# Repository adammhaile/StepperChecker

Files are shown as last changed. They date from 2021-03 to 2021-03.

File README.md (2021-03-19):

# StepperChecker

StepperChecker is  a stepper motor driver dev and test board, designed to be easy to build, setup, and use.
It will take any stepstick style motor driver and any Feather compatible microcontroller board.
The basic intent is to have firmware loaded that will move the motor forward or reverse based on which button is pressed, at a sped defined by the potentiometer. But, of course, the sky is the limit given the many Feather boards available.

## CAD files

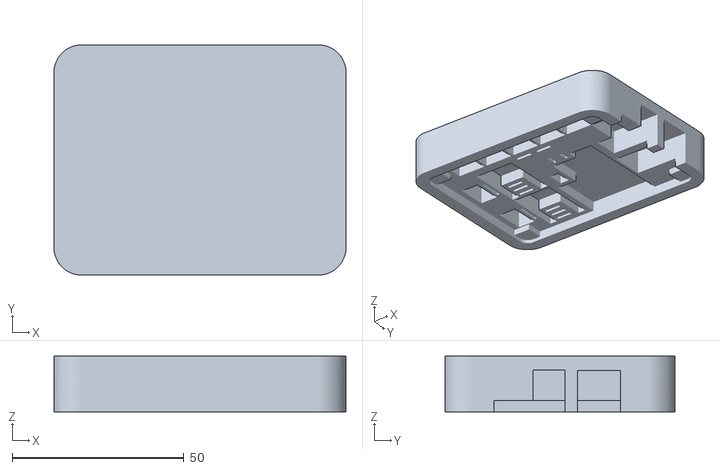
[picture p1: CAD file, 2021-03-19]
StepperChecker/SolderJig.stl
85.0 x 67.0 x 16.2

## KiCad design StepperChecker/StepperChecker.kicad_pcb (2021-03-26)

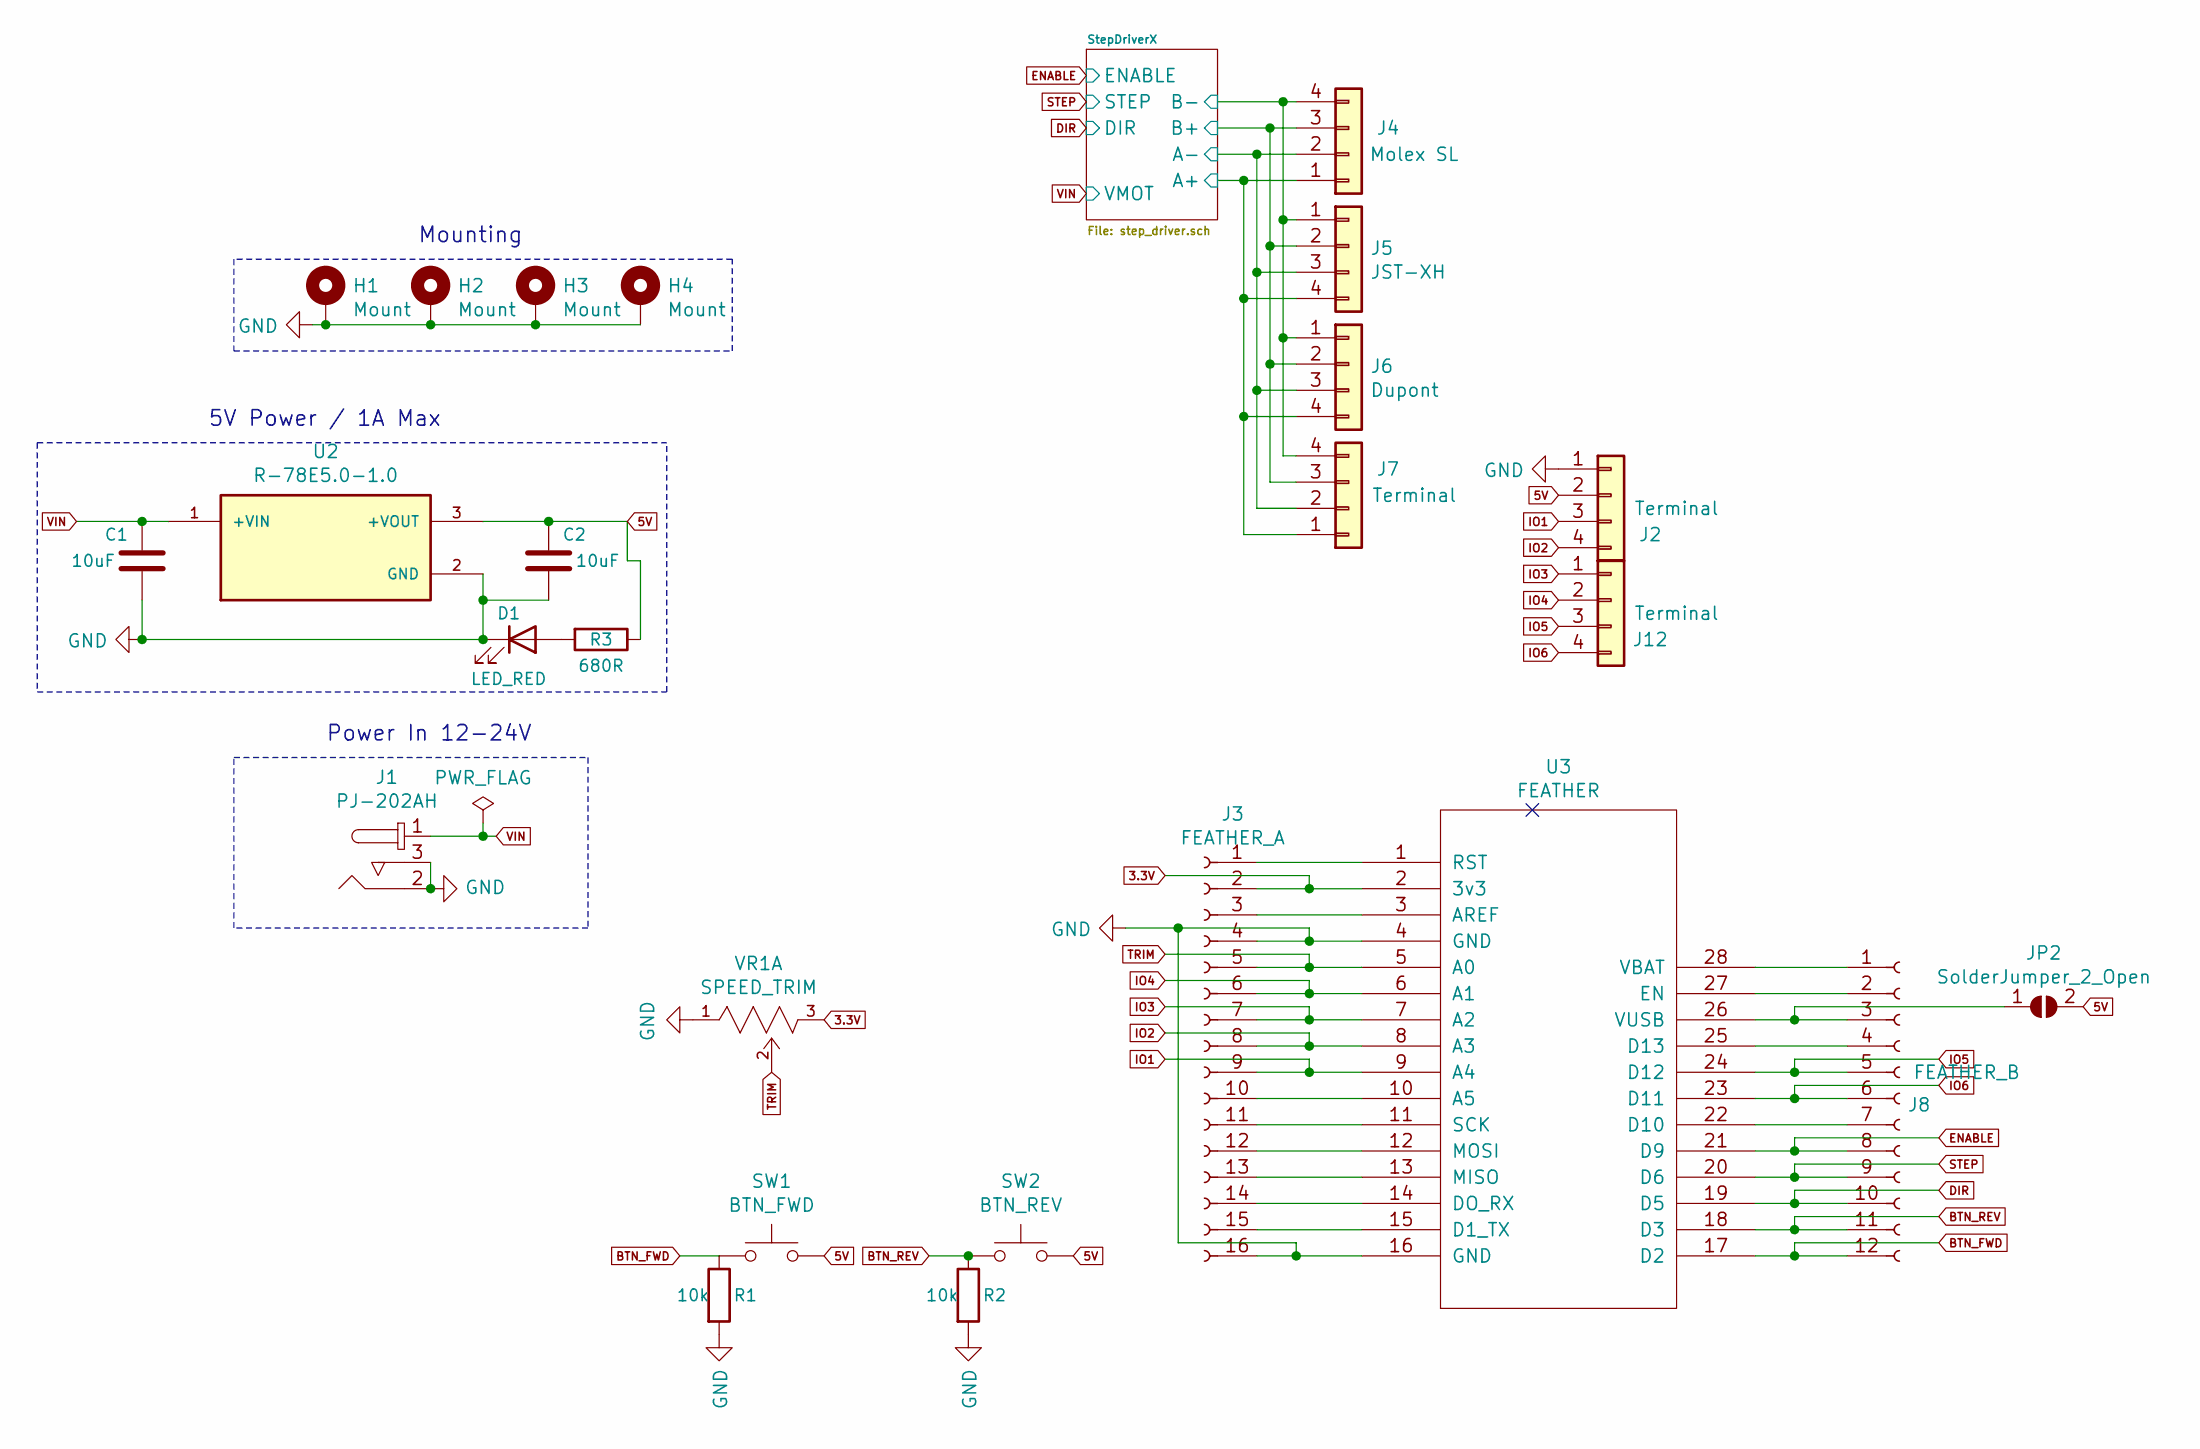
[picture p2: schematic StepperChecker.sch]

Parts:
C1, C2: 10uF; CP_Radial_D5.0mm_P2.00mm
D1: LED_RED; LED_D3.0mm
H1, H2, H3, H4: Mount; MountingHole_2.5mm_Pad
J1: PJ-202AH; Barrel_Jack_5.5mmODx2.1mmID_PJ-202A; MPN PJ-202AH; Digi-Key_PN CP-202AH-ND
J2, J7, J12: Terminal; TerminalBlock_Phoenix_MPT-0,5-4-2.54_1x04_P2.54mm_Horizontal
J3: FEATHER_A; PinSocket_1x16_P2.54mm_Vertical
J4: Molex SL; Molex-70543-0038-0-0-MFG
J5: JST-XH; JST_XH_B4B-XH-A_1x04_P2.50mm_Vertical
J6: Dupont; PinHeader_1x04_P2.54mm_Vertical
J8: FEATHER_B; PinSocket_1x12_P2.54mm_Vertical
JP2: SolderJumper_2_Open; SolderJumper-2_P1.3mm_Open_RoundedPad1.0x1.5mm
R1, R2: 10k; R_Axial_DIN0204_L3.6mm_D1.6mm_P7.62mm_Horizontal; MPN RC0603FR-071KL
R3: 680R; R_Axial_DIN0204_L3.6mm_D1.6mm_P7.62mm_Horizontal; MPN RC0603FR-071KL
SW1: BTN_FWD; SW_PUSH_6mm_H5mm
SW2: BTN_REV; SW_PUSH_6mm_H5mm
U2: R-78E5.0-1.0; CONV_R-78E5.0-1.0; PARTREV 6
U3: FEATHER; Adafruit_Feather
VR1: SPEED_TRIM; ALPS-RK09D1130C3W-0; mouser part number 688-RK09D1130C3W

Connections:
3.3V: J3.2, U3.2 (3v3), VR1.3
5V: C2.1, J2.2, JP2.2 (B), R3.1, SW1.2, SW2.2, U2.3 (+VOUT); also elsewhere on the board
/StepDriverX/A+: J4.1, J5.4, J6.4, J7.1; also elsewhere on the board
/StepDriverX/A-: J4.2, J5.3, J6.3, J7.2; also elsewhere on the board
/StepDriverX/B+: J4.3, J5.2, J6.2, J7.3; also elsewhere on the board
/StepDriverX/B-: J4.4, J5.1, J6.1, J7.4; also elsewhere on the board
BTN_FWD: J8.12, R1.1, SW1.1, U3.17 (D2)
BTN_REV: J8.11, R2.1, SW2.1, U3.18 (D3)
DIR: J8.10, U3.19 (D5); also elsewhere on the board
ENABLE: J8.8, U3.21 (D9); also elsewhere on the board
GND: C1.2, C2.2, D1.1 (K), H1.1, H2.1, H3.1, H4.1, J1.2, J1.3, J2.1, J3.4, J3.16, R1.2, R2.2, U2.2 (GND), U3.4 (GND), U3.16 (GND), VR1.1; also elsewhere on the board
IO1: J2.3, J3.9, U3.9 (A4)
IO2: J2.4, J3.8, U3.8 (A3)
IO3: J3.7, J12.1, U3.7 (A2)
IO4: J3.6, J12.2, U3.6 (A1)
IO5: J8.5, J12.3, U3.24 (D12)
IO6: J8.6, J12.4, U3.23 (D11)
unnamed: D1.2 (A), R3.2
unnamed: J3.1, U3.1 (RST)
unnamed: J3.3, U3.3 (AREF)
unnamed: J3.10, U3.10 (A5)
unnamed: J3.11, U3.11 (SCK)
unnamed: J3.12, U3.12 (MOSI)
unnamed: J3.13, U3.13 (MISO)
unnamed: J3.14, U3.14 (DO_RX)
unnamed: J3.15, U3.15 (D1_TX)
unnamed: J8.1, U3.28 (VBAT)
unnamed: J8.2, U3.27 (EN)
unnamed: J8.3, JP2.1 (A), U3.26 (VUSB)
unnamed: J8.4, U3.25 (D13)
unnamed: J8.7, U3.22 (D10)
STEP: J8.9, U3.20 (D6); also elsewhere on the board
TRIM: J3.5, U3.5 (A0), VR1.2
VIN: C1.1, J1.1, U2.1 (+VIN); also elsewhere on the board

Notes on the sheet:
5V Power / 1A Max
Power In 12-24V
Mounting

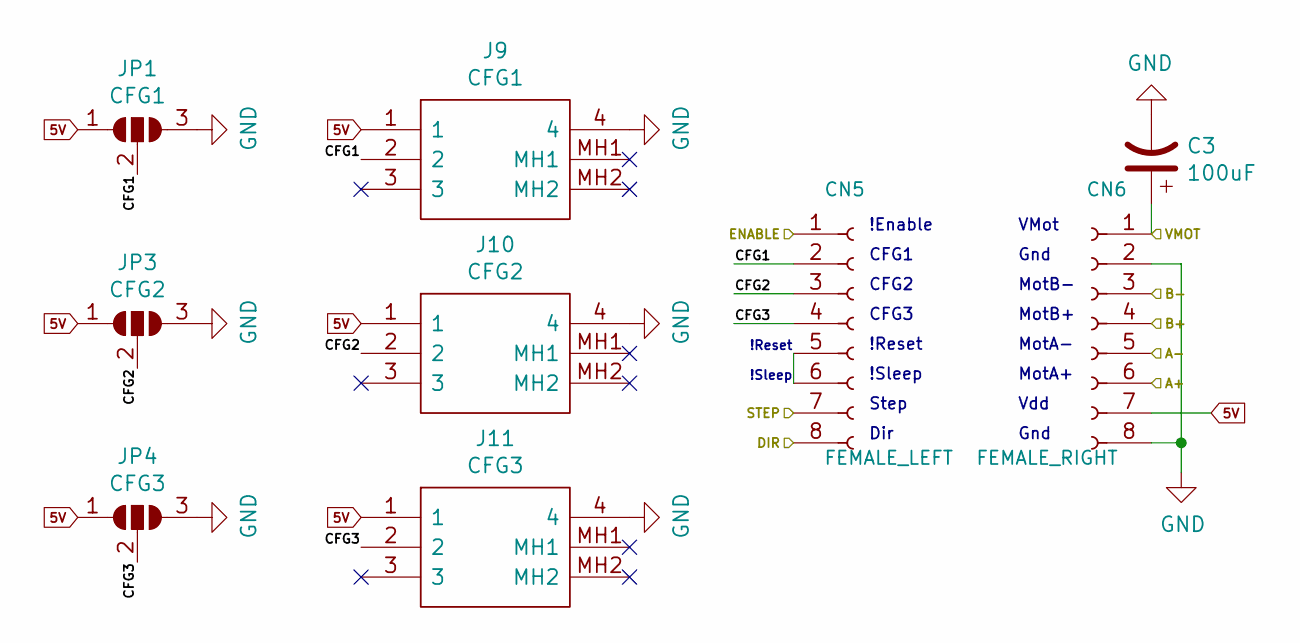
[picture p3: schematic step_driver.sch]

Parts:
C3: 100uF; CP_Radial_D8.0mm_P3.50mm
CN5: FEMALE_LEFT; PinSocket_1x08_P2.54mm_Vertical; MPN F185-1108A1BSYC1
CN6: FEMALE_RIGHT; PinSocket_1x08_P2.54mm_Vertical; MPN F185-1108A1BSYC1
J9: CFG1; OS103012MU1QP1; Mouser Part Number 611-OS103012MU1QP1
J10: CFG2; OS103012MU1QP1; Mouser Part Number 611-OS103012MU1QP1
J11: CFG3; OS103012MU1QP1; Mouser Part Number 611-OS103012MU1QP1
JP1: CFG1; SolderJumper-3_P1.3mm_Open_RoundedPad1.0x1.5mm
JP3: CFG2; SolderJumper-3_P1.3mm_Open_RoundedPad1.0x1.5mm
JP4: CFG3; SolderJumper-3_P1.3mm_Open_RoundedPad1.0x1.5mm

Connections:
5V: CN6.7, J9.1, J10.1, J11.1, JP1.1 (A), JP3.1 (A), JP4.1 (A); also elsewhere on the board
/StepDriverX/A+: CN6.6; also elsewhere on the board
/StepDriverX/A-: CN6.5; also elsewhere on the board
/StepDriverX/B+: CN6.4; also elsewhere on the board
/StepDriverX/B-: CN6.3; also elsewhere on the board
/StepDriverX/CFG1: CN5.2, J9.2, JP1.2 (C)
/StepDriverX/CFG2: CN5.3, J10.2, JP3.2 (C)
/StepDriverX/CFG3: CN5.4, J11.2, JP4.2 (C)
DIR: CN5.8; also elsewhere on the board
ENABLE: CN5.1; also elsewhere on the board
GND: C3.2, CN6.2, CN6.8, J9.4, J10.4, J11.4, JP1.3 (B), JP3.3 (B), JP4.3 (B); also elsewhere on the board
unnamed: CN5.5, CN5.6
STEP: CN5.7; also elsewhere on the board
VIN: C3.1, CN6.1; also elsewhere on the board

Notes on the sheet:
!Reset
!Sleep
!Enable
CFG1
CFG2
CFG3
Step
Dir
VMot
Gnd
MotB-
MotB+
MotA-
MotA+
Vdd

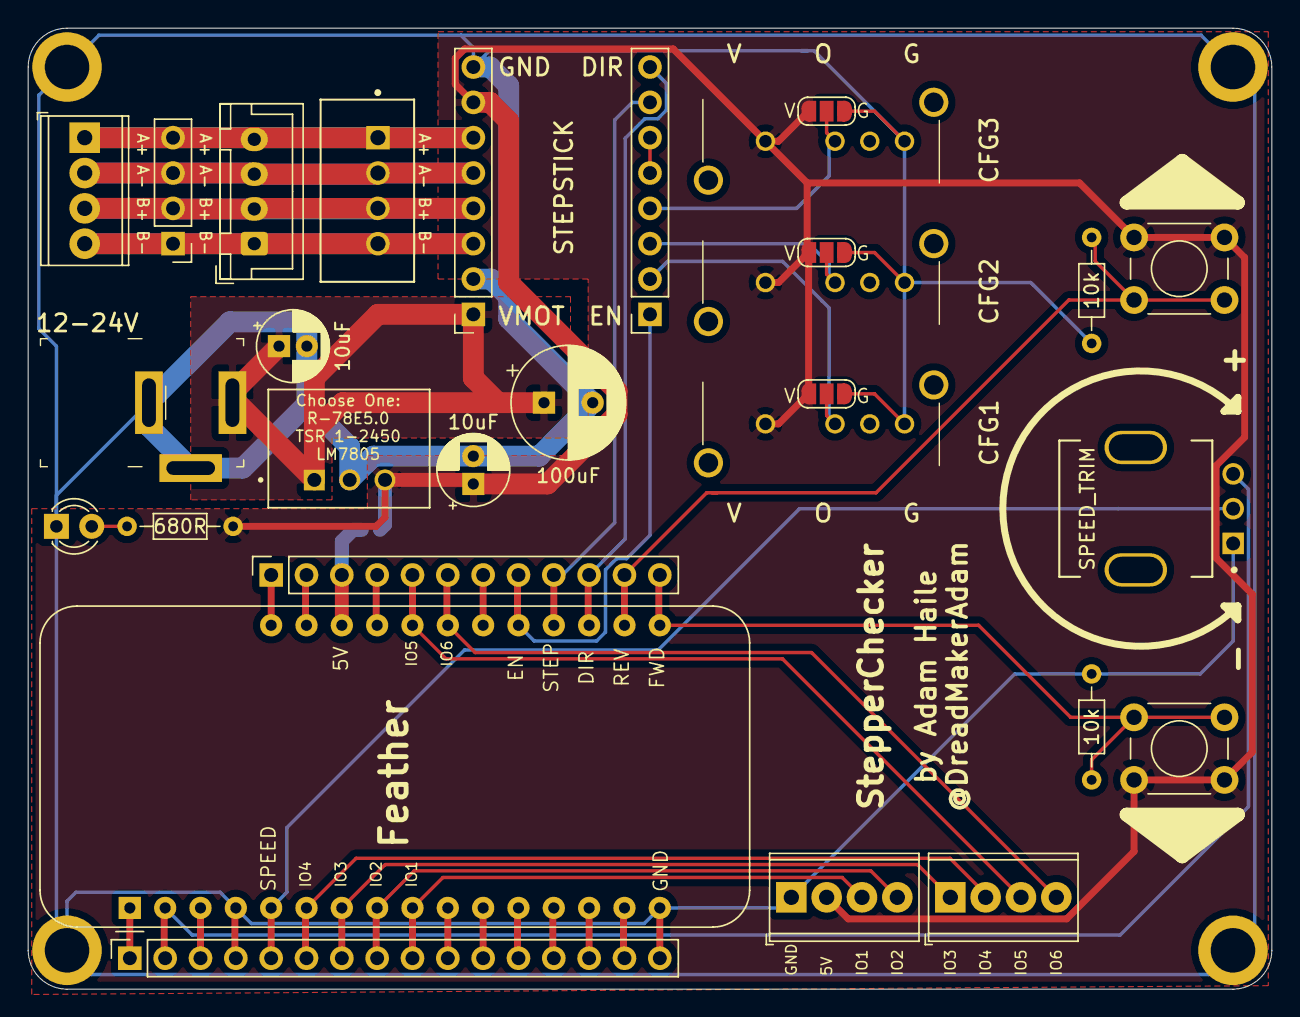
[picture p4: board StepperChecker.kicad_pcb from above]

Board: 2 copper layers, 89.4 x 69.1 mm, 34 parts (1 on the bottom side), 38 nets.

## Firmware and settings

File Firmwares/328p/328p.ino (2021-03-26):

#include "AccelStepper.h"

#define SPEED A0
#define FWD   A4
#define REV   A5
#define STP   6
#define DIR   5
#define ENA   9

#define MAX_SPEED 1600 // max steps/s

int speedVal = 0;
int step_speed = MAX_SPEED;

AccelStepper motor = AccelStepper(AccelStepper::DRIVER, STP);

void setup()
{
    Serial.begin(115200);
    pinMode(SPEED, INPUT);
    pinMode(FWD, INPUT);
    pinMode(REV, INPUT);
    pinMode(STP, OUTPUT);
    pinMode(DIR, OUTPUT);
    pinMode(ENA, OUTPUT);
    digitalWrite(ENA, LOW);
    digitalWrite(DIR, LOW);
    
    motor.setMaxSpeed(MAX_SPEED);
}

void loop()
{
    speedVal = analogRead(SPEED);
    step_speed = map(speedVal, 0, 1023, 0, MAX_SPEED);
    if(digitalRead(FWD))
    {
        digitalWrite(DIR, HIGH);
        motor.setSpeed(step_speed);
        motor.runSpeed();
    }
    else if(digitalRead(REV))
    {
        digitalWrite(DIR, LOW);
        motor.setSpeed(step_speed);
        motor.runSpeed();
    }
}

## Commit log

2021-03-19 Add Recom and jumpers
    [StepperChecker.kicad_pcb, step_driver.sch]
2021-03-19 Fix missing traces and fill
    [StepperChecker.kicad_pcb]
2021-03-20 updated labels
    [StepperChecker.kicad_pcb]
2021-03-26 Minor board tweaks
    [StepperChecker.kicad_pcb, StepperChecker.sch]
